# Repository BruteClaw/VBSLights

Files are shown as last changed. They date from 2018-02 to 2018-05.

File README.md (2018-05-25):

# VBSLights
Lighting modules for VBS

Designes are in KiCAD with corisponding Gerbers

Spec sheets on pertinant components

Code for the Raspberry Pi in Python

lightTest.py is a functional script to test the LEDs on device0

MQTT_Test.py is a functional script to test your MQTT Broker setup

MQTT_Lights.py is the full code that I have implemented on the Raspberry Pi that is in control of the lights

MQTT_Periodic_Test.py is a script that cycles through the commands of MQTT_Lights.py in order to stress test the configuration

MQTT_GUI.py is the code on the touch screen Pi in order to control the lights across the network

tkinter_test.py is some code that I was using to test the ability to make a GUI interface for the touchscreen

Videos of the design process:  https://www.youtube.com/playlist?list=PLKgBsJoH7_7Tdjw1KCGC1FjwnGFgput7B

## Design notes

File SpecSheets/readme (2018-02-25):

These are the spec sheets on components used in the circuit design

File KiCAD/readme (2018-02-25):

These are the project files for KiCAD on the circuit design and layout

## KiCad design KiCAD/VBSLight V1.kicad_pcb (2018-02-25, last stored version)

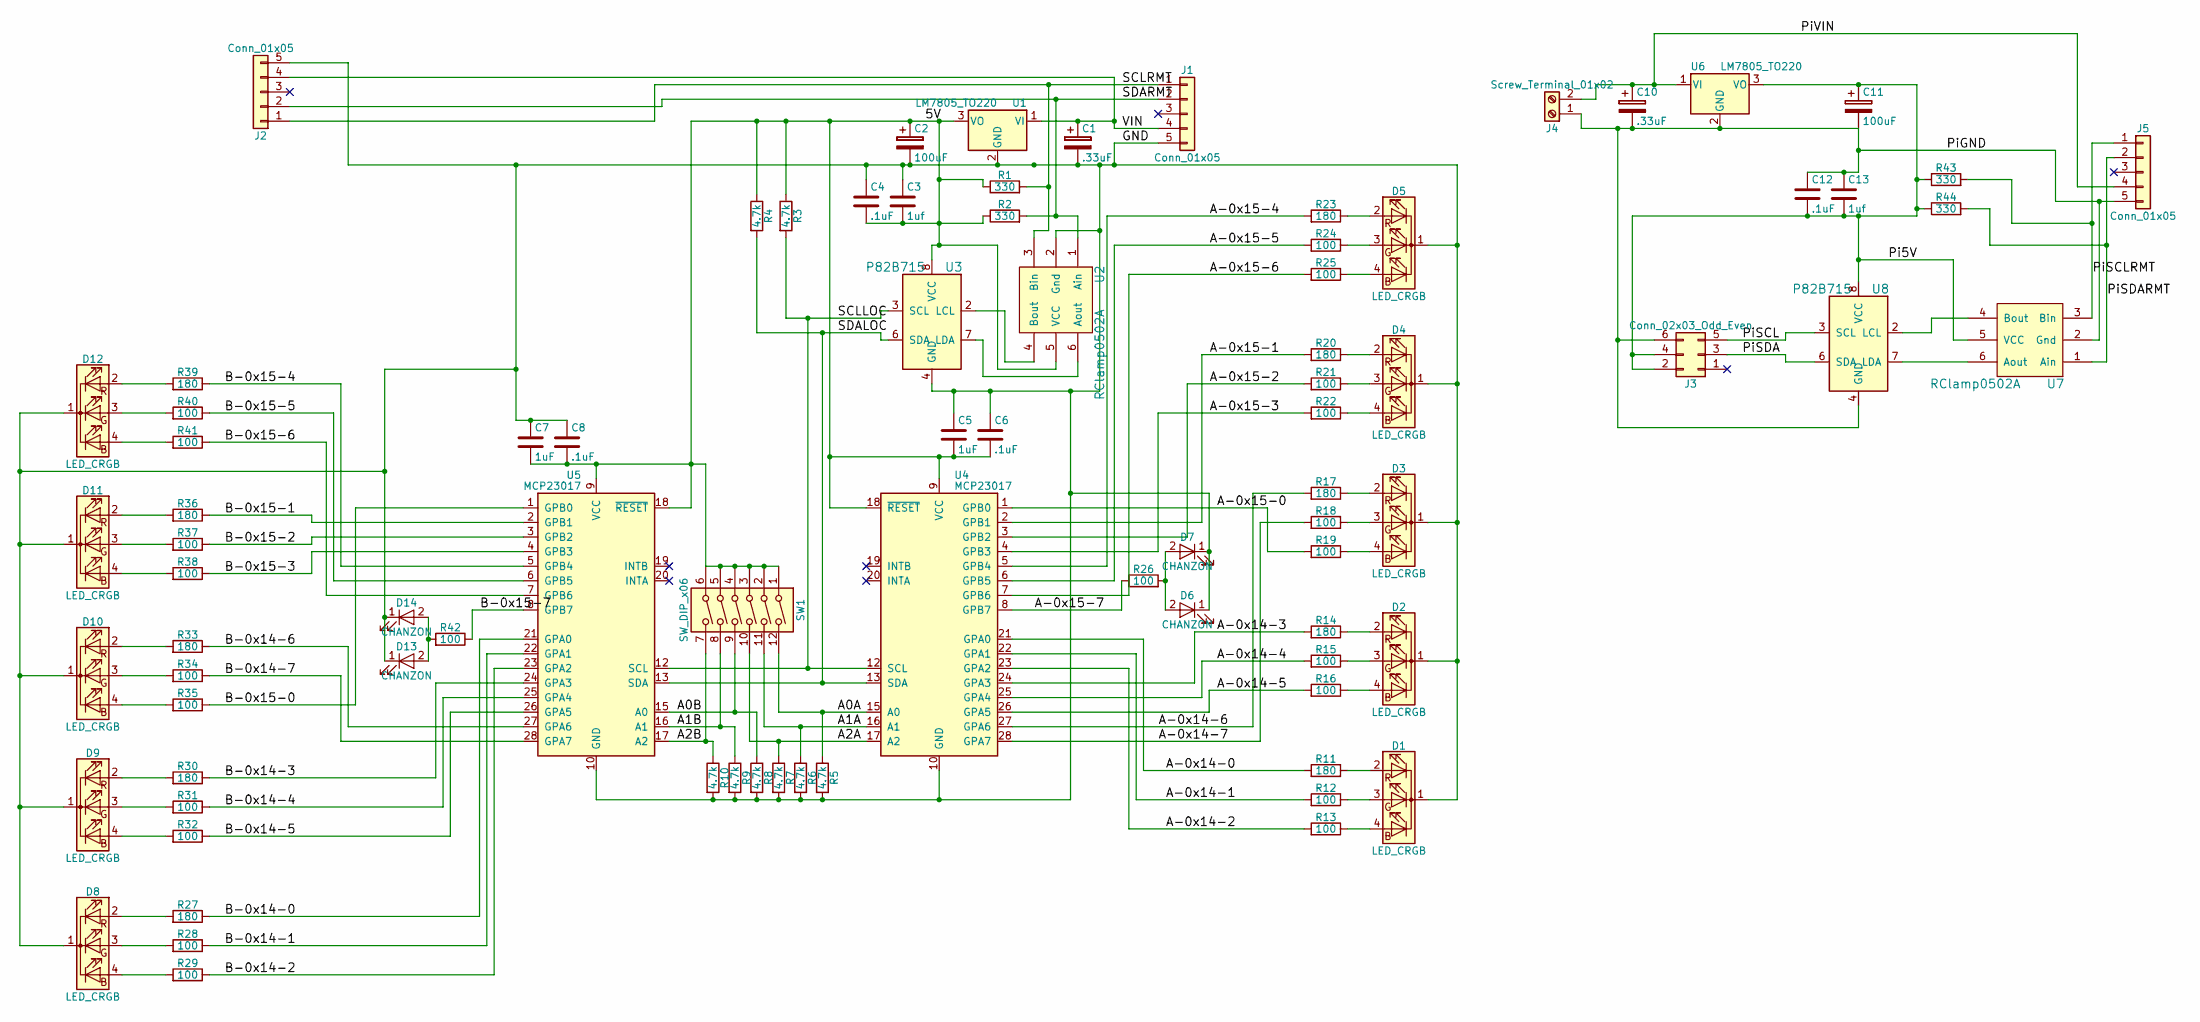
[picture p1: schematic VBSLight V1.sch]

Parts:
C1, C10: .33uF; CP_Radial_D4.0mm_P1.50mm
C2, C11: 100uF; CP_Radial_D4.0mm_P1.50mm
C3, C13: 1uf; C_1210_HandSoldering
C4, C6, C8, C12: .1uF; C_1210_HandSoldering
C5, C7: 1uF; C_1210_HandSoldering
D1, D2, D3, D4, D5, D8, D9, D10, D11, D12: LED_CRGB; LED_D5.0mm-4-Custom
D6, D7, D13, D14: CHANZON; LED_D5.0mm
J1, J2, J5: Conn_01x05; JST_XH_B05B-XH-A_05x2.50mm_Straight
J3: Conn_02x03_Odd_Even; Socket_Strip_Straight_2x03_Pitch2.54mm
J4: Screw_Terminal_01x02; TerminalBlock_Phoenix_MKDS1.5-2pol
R1, R2, R43, R44: 330; R_1210_HandSoldering
R3, R4, R5, R6, R7, R8, R9, R10: 4.7k; R_1210_HandSoldering
R11, R14, R17, R20, R23, R27, R30, R33, R36, R39: 180; R_1210_HandSoldering
R12, R13, R15, R16, R18, R19, R21, R22, R24, R25, R26, R28, R29, R31, R32, R34, R35, R37, R38, R40, R41, R42: 100; R_1210_HandSoldering
SW1: SW_DIP_x06; SW_DIP_x6_W7.62mm_Slide
U1, U6: LM7805_TO220; TO-220-3_Vertical
U2, U7: RClamp0502A; SOT-666_Handsolder
U3, U8: P82B715; SOIC-8-N
U4, U5: MCP23017; SOIC-28

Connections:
/5V: C2.1, C3.2, C4.2, C5.2, C6.2, C7.2, C8.2, R1.1, R2.1, R3.1, R4.1, SW1.1, SW1.2, SW1.3, SW1.4, SW1.5, SW1.6, U1.3 (VO), U2.5 (VCC), U3.8 (VCC), U4.9 (VCC), U4.18 (~RESET), U5.9 (VCC), U5.18 (~RESET)
/A0A: R5.1, SW1.12, U4.15 (A0)
/A0B: R8.1, SW1.9, U5.15 (A0)
/A1A: R6.1, SW1.11, U4.16 (A1)
/A1B: R9.1, SW1.8, U5.16 (A1)
/A2A: R7.1, SW1.10, U4.17 (A2)
/A2B: R10.1, SW1.7, U5.17 (A2)
/A-0x14-0: R11.2, U4.21 (GPA0)
/A-0x14-1: R12.2, U4.22 (GPA1)
/A-0x14-2: R13.2, U4.23 (GPA2)
/A-0x14-3: R14.2, U4.24 (GPA3)
/A-0x14-4: R15.2, U4.25 (GPA4)
/A-0x14-5: R16.2, U4.26 (GPA5)
/A-0x14-6: R17.2, U4.27 (GPA6)
/A-0x14-7: R18.2, U4.28 (GPA7)
/A-0x15-0: R19.2, U4.1 (GPB0)
/A-0x15-1: R20.2, U4.2 (GPB1)
/A-0x15-2: R21.2, U4.3 (GPB2)
/A-0x15-3: R22.2, U4.4 (GPB3)
/A-0x15-4: R23.2, U4.5 (GPB4)
/A-0x15-5: R24.2, U4.6 (GPB5)
/A-0x15-6: R25.2, U4.7 (GPB6)
/A-0x15-7: R26.1, U4.8 (GPB7)
/B-0x14-0: R27.1, U5.21 (GPA0)
/B-0x14-1: R28.1, U5.22 (GPA1)
/B-0x14-2: R29.1, U5.23 (GPA2)
/B-0x14-3: R30.1, U5.24 (GPA3)
/B-0x14-4: R31.1, U5.25 (GPA4)
/B-0x14-5: R32.1, U5.26 (GPA5)
/B-0x14-6: R33.1, U5.27 (GPA6)
/B-0x14-7: R34.1, U5.28 (GPA7)
/B-0x15-0: R35.1, U5.1 (GPB0)
/B-0x15-1: R36.1, U5.2 (GPB1)
/B-0x15-2: R37.1, U5.3 (GPB2)
/B-0x15-3: R38.1, U5.4 (GPB3)
/B-0x15-4: R39.1, U5.5 (GPB4)
/B-0x15-5: R40.1, U5.6 (GPB5)
/B-0x15-6: R41.1, U5.7 (GPB6)
/B-0x15-7: R42.1, U5.8 (GPB7)
/GND: C1.2, C2.2, C3.1, C4.1, C5.1, C6.1, C7.1, C8.1, D1.1 (K), D2.1 (K), D3.1 (K), D4.1 (K), D5.1 (K), D6.1 (K), D7.1 (K), D8.1 (K), D9.1 (K), D10.1 (K), D11.1 (K), D12.1 (K), D13.1 (K), D14.1 (K), J1.5, J2.5, R5.2, R6.2, R7.2, R8.2, R9.2, R10.2, U1.2 (GND), U2.2 (Gnd), U3.4 (GND), U4.10 (GND), U5.10 (GND)
/Pi5V: C11.1, C12.2, C13.2, J3.2, J3.4, R43.1, R44.1, U6.3 (VO), U7.5 (VCC), U8.8 (VCC); also elsewhere on the board
/PiGND: C10.2, C11.2, C12.1, C13.1, J3.6, J4.1, J5.5, U6.2 (GND), U7.2 (Gnd), U8.4 (GND)
/PiSCL: J3.5, U8.3 (SCL)
/PiSCLRMT: J5.1, R43.2, U7.3 (Bin)
/PiSDA: J3.3, U8.6 (SDA)
/PiSDARMT: J5.2, R44.2, U7.1 (Ain)
/PiVIN: C10.1, J4.2, J5.4, U6.1 (VI)
/SCLLOC: R3.2, U3.3 (SCL), U4.12 (SCL), U5.12 (SCL)
/SCLRMT: J1.1, J2.1, R1.2, U2.3 (Bin)
/SDALOC: R4.2, U3.6 (SDA), U4.13 (SDA), U5.13 (SDA)
/SDARMT: J1.2, J2.2, R2.2, U2.1 (Ain)
/VIN: C1.1, J1.4, J2.4, U1.1 (VI)
unnamed: D1.2 (RA), R11.1
unnamed: D1.3 (GA), R12.1
unnamed: D1.4 (BA), R13.1
unnamed: D2.2 (RA), R14.1
unnamed: D2.3 (GA), R15.1
unnamed: D2.4 (BA), R16.1
unnamed: D3.2 (RA), R17.1
unnamed: D3.3 (GA), R18.1
unnamed: D3.4 (BA), R19.1
unnamed: D4.2 (RA), R20.1
unnamed: D4.3 (GA), R21.1
unnamed: D4.4 (BA), R22.1
unnamed: D5.2 (RA), R23.1
unnamed: D5.3 (GA), R24.1
unnamed: D5.4 (BA), R25.1
unnamed: D6.2 (A), D7.2 (A), R26.2
unnamed: D8.2 (RA), R27.2
unnamed: D8.3 (GA), R28.2
unnamed: D8.4 (BA), R29.2
unnamed: D9.2 (RA), R30.2
unnamed: D9.3 (GA), R31.2
unnamed: D9.4 (BA), R32.2
unnamed: D10.2 (RA), R33.2
unnamed: D10.3 (GA), R34.2
unnamed: D10.4 (BA), R35.2
unnamed: D11.2 (RA), R36.2
unnamed: D11.3 (GA), R37.2
unnamed: D11.4 (BA), R38.2
unnamed: D12.2 (RA), R39.2
unnamed: D12.3 (GA), R40.2
unnamed: D12.4 (BA), R41.2
unnamed: D13.2 (A), D14.2 (A), R42.2
unnamed: U2.4 (Bout), U3.2 (LCL)
unnamed: U2.6 (Aout), U3.7 (LDA)
unnamed: U7.4 (Bout), U8.2 (LCL)
unnamed: U7.6 (Aout), U8.7 (LDA)

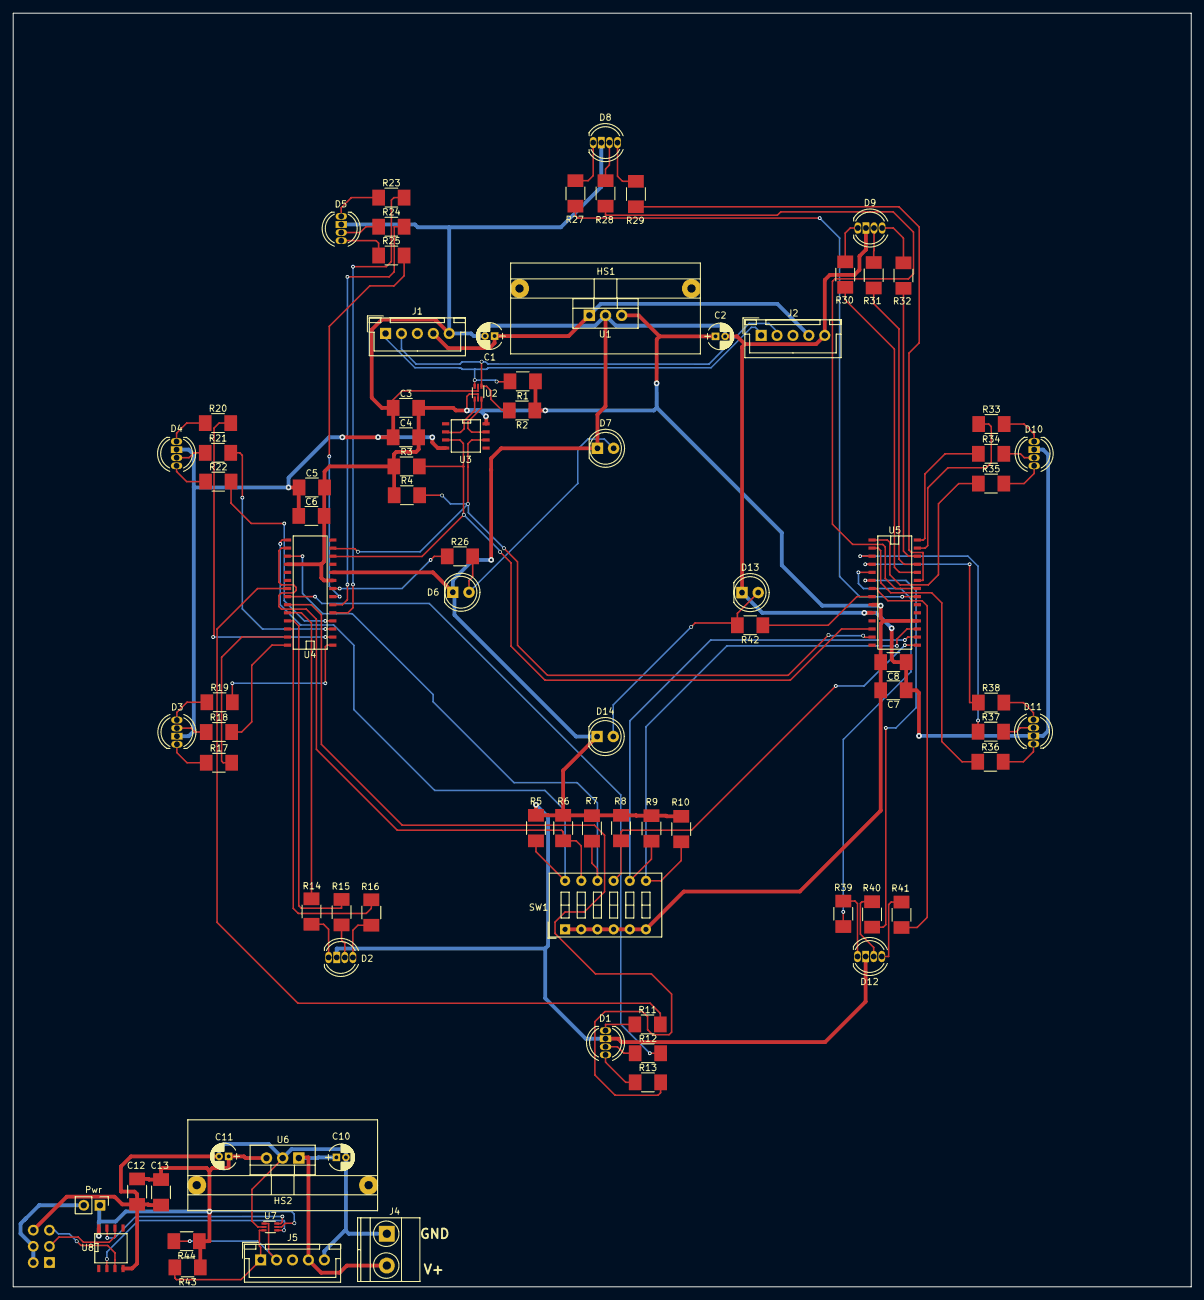
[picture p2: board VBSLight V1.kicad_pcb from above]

Board: 2 copper layers, 185.0 x 200.0 mm, 87 parts (1 on the bottom side), 88 nets.

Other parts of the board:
HS1, HS2: Heatsink_OHMITE_CSM222-30AE; Heatsink_Ohmite_CSM222-30AE
Pwr: Socket_Strip_Straight_1x02_Pitch2.54mm

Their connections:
/Pi5V: Pwr.1, Pwr.2; also elsewhere on the board

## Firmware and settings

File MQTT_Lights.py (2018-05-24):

#!/usr/bin/env python3

#imports
import smbus
import time
import socket
import random
import paho.mqtt.client as paho

#variables
bus       = smbus.SMBus(1) # use 1 for Rev 2 Pi, Use 0 for Rev 1 Pi
swirlTime = 0.1            # how quick the swirl patern runs
blinkTime = 0.2            # how fast the lights blink
broker    = "127.0.0.1"    # address of MQTT Broker
waitTime  = 10             # how long it waits before going Idle

# Device Addresses
devices = [ 0x20, 0x21, 0x22, 0x23, 0x24, 0x25, 0x26, 0x27, ]
# Use only one device for testing, comment out to use all
# devices = [ 0x20 ]

colors = [ "red", "yellow", "green", "blue", "purple", "white", "lightblue", ]

# Registers A are for GPA pins, Registers B are for GPB pins
IODIRA = 0x00 # Register A for pin direction
IODIRB = 0x01 # Register B for pin direction
OLATA  = 0x14 # Register A for outputs
OLATB  = 0x15 # Register B for outputs

banks = [ OLATA, OLATB, ]
random.seed()

#functions
def setup(device):
    # print(f"Setting up device #0x{device}")
    # Set GPA and GPB pins to outputs
    bus.write_byte_data(device,IODIRA,0x00)
    bus.write_byte_data(device,IODIRB,0x00)
    # Set all outputs to off
    bus.write_byte_data(device,OLATA,0x00)
    bus.write_byte_data(device,OLATB,0x00)
    #set lights to idle state
    idleState(device)

#light animations
def clear(addr):
    bus.write_byte_data(addr,OLATA,0x00)
    bus.write_byte_data(addr,OLATB,0x00)

def errorState():
    purpleBlink(devices[0])

def idleState(addr):
    bus.write_byte_data(addr,OLATB,0x80)

#Blinks
def redBlink(addr):
    bus.write_byte_data(addr,OLATA,0x49)
    bus.write_byte_data(addr,OLATB,0x12)
    time.sleep(blinkTime)
    bus.write_byte_data(addr,OLATA,0x00)
    bus.write_byte_data(addr,OLATB,0x00)
    time.sleep(blinkTime)

def blueBlink(addr):
    bus.write_byte_data(addr,OLATA,0x92)
    bus.write_byte_data(addr,OLATB,0x24)
    time.sleep(blinkTime)
    bus.write_byte_data(addr,OLATA,0x00)
    bus.write_byte_data(addr,OLATB,0x00)
    time.sleep(blinkTime)

def purpleBlink(addr):
    bus.write_byte_data(addr,OLATA,0xDB)
    bus.write_byte_data(addr,OLATB,0x36)
    time.sleep(blinkTime)
    bus.write_byte_data(addr,OLATA,0x00)
    bus.write_byte_data(addr,OLATB,0x00)
    time.sleep(blinkTime)

def greenBlink(addr):
    bus.write_byte_data(addr,OLATA,0x24)
    bus.write_byte_data(addr,OLATB,0x49)
    time.sleep(blinkTime)
    bus.write_byte_data(addr,OLATA,0x00)
    bus.write_byte_data(addr,OLATB,0x00)
    time.sleep(blinkTime)

def yellowBlink(addr):
    bus.write_byte_data(addr,OLATA,0x6D)
    bus.write_byte_data(addr,OLATB,0x5B)
    time.sleep(blinkTime)
    bus.write_byte_data(addr,OLATA,0x00)
    bus.write_byte_data(addr,OLATB,0x00)
    time.sleep(blinkTime)

def lightBlueBlink(addr):
    bus.write_byte_data(addr,OLATA,0xB6)
    bus.write_byte_data(addr,OLATB,0x6D)
    time.sleep(blinkTime)
    bus.write_byte_data(addr,OLATA,0x00)
    bus.write_byte_data(addr,OLATB,0x00)
    time.sleep(blinkTime)

def whiteBlink(addr):
    bus.write_byte_data(addr,OLATA,0xFF)
    bus.write_byte_data(addr,OLATB,0x7F)
    time.sleep(blinkTime)
    bus.write_byte_data(addr,OLATA,0x00)
    bus.write_byte_data(addr,OLATB,0x00)
    time.sleep(blinkTime)

#Swirls
def redSwirl(addr):
    bus.write_byte_data(addr,OLATA,0x01)
    time.sleep(swirlTime)
    bus.write_byte_data(addr,OLATA,0x08)
    time.sleep(swirlTime)
    bus.write_byte_data(addr,OLATA,0x40)
    time.sleep(swirlTime)
    bus.write_byte_data(addr,OLATA,0x00)
    bus.write_byte_data(addr,OLATB,0x02)
    time.sleep(swirlTime)
    bus.write_byte_data(addr,OLATB,0x10)
    time.sleep(swirlTime)
    bus.write_byte_data(addr,OLATB,0x00)
    time.sleep(swirlTime)

def blueSwirl(addr):
    bus.write_byte_data(addr,OLATA,0x02)
    time.sleep(swirlTime)
    bus.write_byte_data(addr,OLATA,0x10)
    time.sleep(swirlTime)
    bus.write_byte_data(addr,OLATA,0x80)
    time.sleep(swirlTime)
    bus.write_byte_data(addr,OLATA,0x00)
    bus.write_byte_data(addr,OLATB,0x04)
    time.sleep(swirlTime)
    bus.write_byte_data(addr,OLATB,0x20)
    time.sleep(swirlTime)
    bus.write_byte_data(addr,OLATB,0x00)
    time.sleep(swirlTime)

def greenSwirl(addr):
    bus.write_byte_data(addr,OLATA,0x04)
    time.sleep(swirlTime)
    bus.write_byte_data(addr,OLATA,0x20)
    time.sleep(swirlTime)
    bus.write_byte_data(addr,OLATA,0x00)
    bus.write_byte_data(addr,OLATB,0x01)
    time.sleep(swirlTime)
    bus.write_byte_data(addr,OLATB,0x08)
    time.sleep(swirlTime)
    bus.write_byte_data(addr,OLATB,0x40)
    time.sleep(swirlTime)
    bus.write_byte_data(addr,OLATB,0x00)
    time.sleep(swirlTime)

def purpleSwirl(addr):
    bus.write_byte_data(addr,OLATA,0x03)
    time.sleep(swirlTime)
    bus.write_byte_data(addr,OLATA,0x18)
    time.sleep(swirlTime)
    bus.write_byte_data(addr,OLATA,0xc0)
    time.sleep(swirlTime)
    bus.write_byte_data(addr,OLATA,0x00)
    bus.write_byte_data(addr,OLATB,0x06)
    time.sleep(swirlTime)
    bus.write_byte_data(addr,OLATB,0x30)
    time.sleep(swirlTime)
    bus.write_byte_data(addr,OLATB,0x00)
    time.sleep(swirlTime)

def yellowSwirl(addr):
    bus.write_byte_data(addr,OLATA,0x05)
    time.sleep(swirlTime)
    bus.write_byte_data(addr,OLATA,0x28)
    time.sleep(swirlTime)
    bus.write_byte_data(addr,OLATA,0x40)
    bus.write_byte_data(addr,OLATB,0x01)
    time.sleep(swirlTime)
    bus.write_byte_data(addr,OLATA,0x00)
    bus.write_byte_data(addr,OLATB,0x0A)
    time.sleep(swirlTime)
    bus.write_byte_data(addr,OLATB,0x50)
    time.sleep(swirlTime)
    bus.write_byte_data(addr,OLATB,0x00)
    time.sleep(swirlTime)

def lightBlueSwirl(addr):
    bus.write_byte_data(addr,OLATA,0x06)
    time.sleep(swirlTime)
    bus.write_byte_data(addr,OLATA,0x30)
    time.sleep(swirlTime)
    bus.write_byte_data(addr,OLATA,0x80)
    bus.write_byte_data(addr,OLATB,0x01)
    time.sleep(swirlTime)
    bus.write_byte_data(addr,OLATA,0x00)
    bus.write_byte_data(addr,OLATB,0x0C)
    time.sleep(swirlTime)
    bus.write_byte_data(addr,OLATB,0x60)
    time.sleep(swirlTime)
    bus.write_byte_data(addr,OLATB,0x00)
    time.sleep(swirlTime)

def whiteSwirl(addr):
    bus.write_byte_data(addr,OLATA,0x07)
    time.sleep(swirlTime)
    bus.write_byte_data(addr,OLATA,0x38)
    time.sleep(swirlTime)
    bus.write_byte_data(addr,OLATA,0xC0)
    bus.write_byte_data(addr,OLATB,0x01)
    time.sleep(swirlTime)
    bus.write_byte_data(addr,OLATA,0x00)
    bus.write_byte_data(addr,OLATB,0x0E)
    time.sleep(swirlTime)
    bus.write_byte_data(addr,OLATB,0x70)
    time.sleep(swirlTime)
    bus.write_byte_data(addr,OLATB,0x00)
    time.sleep(swirlTime)

#test sequince
def test():
    lightBlueBlink(devices[0])
    lightBlueSwirl(devices[0])
    idleState(devices[0])
    lightBlueBlink(devices[1])
    lightBlueSwirl(devices[1])
    idleState(devices[1])
    lightBlueBlink(devices[2])
    lightBlueSwirl(devices[2])
    idleState(devices[2])
    lightBlueBlink(devices[3])
    lightBlueSwirl(devices[3])
    idleState(devices[3])
    lightBlueBlink(devices[4])
    lightBlueSwirl(devices[4])
    idleState(devices[4])
    lightBlueBlink(devices[5])
    lightBlueSwirl(devices[5])
    idleState(devices[5])
    lightBlueBlink(devices[6])
    lightBlueSwirl(devices[6])
    idleState(devices[6])
    lightBlueBlink(devices[7])
    lightBlueSwirl(devices[7])
    idleState(devices[7])
    blueBlink(devices[0])
    blueSwirl(devices[0])
    idleState(devices[0])
    blueBlink(devices[1])
    blueSwirl(devices[1])
    idleState(devices[1])
    blueBlink(devices[2])
    blueSwirl(devices[2])
    idleState(devices[2])
    blueBlink(devices[3])
    blueSwirl(devices[3])
    idleState(devices[3])
    blueBlink(devices[4])
    blueSwirl(devices[4])
    idleState(devices[4])
    blueBlink(devices[5])
    blueSwirl(devices[5])
    idleState(devices[5])
    blueBlink(devices[6])
    blueSwirl(devices[6])
    idleState(devices[6])
    blueBlink(devices[7])
    blueSwirl(devices[7])
    idleState(devices[7])
    purpleBlink(devices[0])
    purpleSwirl(devices[0])
    idleState(devices[0])
    purpleBlink(devices[1])
    purpleSwirl(devices[1])
    idleState(devices[1])
    purpleBlink(devices[2])
    purpleSwirl(devices[2])
    idleState(devices[2])
    purpleBlink(devices[3])
    purpleSwirl(devices[3])
    idleState(devices[3])
    purpleBlink(devices[4])
    purpleSwirl(devices[4])
    idleState(devices[4])
    purpleBlink(devices[5])
    purpleSwirl(devices[5])
    idleState(devices[5])
    purpleBlink(devices[6])
    purpleSwirl(devices[6])
    idleState(devices[6])
    purpleBlink(devices[7])
    purpleSwirl(devices[7])
    idleState(devices[7])
    redBlink(devices[0])
    redSwirl(devices[0])
    idleState(devices[0])
    redBlink(devices[1])
    redSwirl(devices[1])
    idleState(devices[1])
    redBlink(devices[2])
    redSwirl(devices[2])
    idleState(devices[2])
    redBlink(devices[3])
    redSwirl(devices[3])
    idleState(devices[3])
    redBlink(devices[4])
    redSwirl(devices[4])
    idleState(devices[4])
    redBlink(devices[5])
    redSwirl(devices[5])
    idleState(devices[5])
    redBlink(devices[6])
    redSwirl(devices[6])
    idleState(devices[6])
    redBlink(devices[7])
    redSwirl(devices[7])
    idleState(devices[7])
    yellowBlink(devices[0])
    yellowSwirl(devices[0])
    idleState(devices[0])
    yellowBlink(devices[1])
    yellowSwirl(devices[1])
    idleState(devices[1])
    yellowBlink(devices[2])
    yellowSwirl(devices[2])
    idleState(devices[2])
    yellowBlink(devices[3])
    yellowSwirl(devices[3])
    idleState(devices[3])
    yellowBlink(devices[4])
    yellowSwirl(devices[4])
    idleState(devices[4])
    yellowBlink(devices[5])
    yellowSwirl(devices[5])
    idleState(devices[5])
    yellowBlink(devices[6])
    yellowSwirl(devices[6])
    idleState(devices[6])
    yellowBlink(devices[7])
    yellowSwirl(devices[7])
    idleState(devices[7])
    greenBlink(devices[0])
    greenSwirl(devices[0])
    idleState(devices[0])
    greenBlink(devices[1])
    greenSwirl(devices[1])
    idleState(devices[1])
    greenBlink(devices[2])
    greenSwirl(devices[2])
    idleState(devices[2])
    greenBlink(devices[3])
    greenSwirl(devices[3])
    idleState(devices[3])
    greenBlink(devices[4])
    greenSwirl(devices[4])
    idleState(devices[4])
    greenBlink(devices[5])
    greenSwirl(devices[5])
    idleState(devices[5])
    greenBlink(devices[6])
    greenSwirl(devices[6])
    idleState(devices[6])
    greenBlink(devices[7])
    greenSwirl(devices[7])
    idleState(devices[7])
    whiteBlink(devices[0])
    whiteSwirl(devices[0])
    idleState(devices[0])
    whiteBlink(devices[1])
    whiteSwirl(devices[1])
    idleState(devices[1])
    whiteBlink(devices[2])
    whiteSwirl(devices[2])
    idleState(devices[2])
    whiteBlink(devices[3])
    whiteSwirl(devices[3])
    idleState(devices[3])
    whiteBlink(devices[4])
    whiteSwirl(devices[4])
    idleState(devices[4])
    whiteBlink(devices[5])
    whiteSwirl(devices[5])
    idleState(devices[5])
    whiteBlink(devices[6])
    whiteSwirl(devices[6])
    idleState(devices[6])
    whiteBlink(devices[7])
    whiteSwirl(devices[7])
    idleState(devices[7])

#animations for years
def rampUp():
    allClear()
    bus.write_byte_data(devices[0],OLATA,0x05)
    bus.write_byte_data(devices[1],OLATA,0x05)
    time.sleep(swirlTime)
    bus.write_byte_data(devices[0],OLATA,0x28)
    bus.write_byte_data(devices[1],OLATA,0x28)
    bus.write_byte_data(devices[2],OLATA,0x05)
    time.sleep(swirlTime)
    bus.write_byte_data(devices[0],OLATA,0x40)
    bus.write_byte_data(devices[0],OLATB,0x01)
    bus.write_byte_data(devices[1],OLATA,0x40)
    bus.write_byte_data(devices[1],OLATB,0x01)
    bus.write_byte_data(devices[2],OLATA,0x28)
    bus.write_byte_data(devices[3],OLATA,0x05)
    time.sleep(swirlTime)
    bus.write_byte_data(devices[0],OLATA,0x00)
    bus.write_byte_data(devices[0],OLATB,0x0A)
    bus.write_byte_data(devices[1],OLATA,0x00)
    bus.write_byte_data(devices[1],OLATB,0x0A)
    bus.write_byte_data(devices[2],OLATA,0x40)
    bus.write_byte_data(devices[2],OLATB,0x01)
    bus.write_byte_data(devices[3],OLATA,0x28)
    bus.write_byte_data(devices[4],OLATA,0x05)
    time.sleep(swirlTime)
    bus.write_byte_data(devices[0],OLATB,0x50)
    bus.write_byte_data(devices[1],OLATB,0x50)
    bus.write_byte_data(devices[2],OLATA,0x00)
    bus.write_byte_data(devices[2],OLATB,0x0A)
    bus.write_byte_data(devices[3],OLATA,0x40)
    bus.write_byte_data(devices[3],OLATB,0x01)
    bus.write_byte_data(devices[4],OLATA,0x28)
    bus.write_byte_data(devices[5],OLATA,0x05)  
    time.sleep(swirlTime)
    bus.write_byte_data(devices[0],OLATB,0x00)
    bus.write_byte_data(devices[1],OLATB,0x00)
    bus.write_byte_data(devices[0],OLATA,0x05)
    bus.write_byte_data(devices[1],OLATA,0x05)
    bus.write_byte_data(devices[2],OLATB,0x50)
    bus.write_byte_data(devices[3],OLATA,0x00)
    bus.write_byte_data(devices[3],OLATB,0x0A)
    bus.write_byte_data(devices[4],OLATA,0x40)
    bus.write_byte_data(devices[4],OLATB,0x01)
    bus.write_byte_data(devices[5],OLATA,0x28)
    bus.write_byte_data(devices[6],OLATA,0x05) 
    time.sleep(swirlTime)
    bus.write_byte_data(devices[0],OLATA,0x28)
    bus.write_byte_data(devices[1],OLATA,0x28)
    bus.write_byte_data(devices[2],OLATB,0x00)
    bus.write_byte_data(devices[2],OLATA,0x05)
    bus.write_byte_data(devices[3],OLATB,0x50)
    bus.write_byte_data(devices[4],OLATA,0x00)
    bus.write_byte_data(devices[4],OLATB,0x0A)
    bus.write_byte_data(devices[5],OLATA,0x40)
    bus.write_byte_data(devices[5],OLATB,0x01)
    bus.write_byte_data(devices[6],OLATA,0x28)
    bus.write_byte_data(devices[7],OLATA,0x05)
    time.sleep(swirlTime)
    
def fullSwirl():
    bus.write_byte_data(devices[2],OLATA,0x28)
    bus.write_byte_data(devices[3],OLATB,0x00)
    bus.write_byte_data(devices[3],OLATA,0x05)
    bus.write_byte_data(devices[4],OLATB,0x50)
    bus.write_byte_data(devices[5],OLATA,0x00)
    bus.write_byte_data(devices[5],OLATB,0x0A)
    bus.write_byte_data(devices[6],OLATA,0x40)
    bus.write_byte_data(devices[6],OLATB,0x01)
    bus.write_byte_data(devices[7],OLATA,0x28)
    bus.write_byte_data(devices[1],OLATB,0x00)
    bus.write_byte_data(devices[1],OLATA,0x05)
    bus.write_byte_data(devices[0],OLATB,0x00)
    bus.write_byte_data(devices[0],OLATA,0x05)
    time.sleep(swirlTime)
    bus.write_byte_data(devices[3],OLATA,0x28)
    bus.write_byte_data(devices[4],OLATB,0x00)
    bus.write_byte_data(devices[4],OLATA,0x05)
    bus.write_byte_data(devices[5],OLATB,0x50)
    bus.write_byte_data(devices[6],OLATA,0x00)
    bus.write_byte_data(devices[6],OLATB,0x0A)
    bus.write_byte_data(devices[7],OLATA,0x40)
    bus.write_byte_data(devices[7],OLATB,0x01)
    bus.write_byte_data(devices[1],OLATA,0x28)
    bus.write_byte_data(devices[2],OLATB,0x00)
    bus.write_byte_data(devices[2],OLATA,0x05)
    bus.write_byte_data(devices[0],OLATA,0x28)
    time.sleep(swirlTime)
    bus.write_byte_data(devices[4],OLATA,0x28)
    bus.write_byte_data(devices[5],OLATB,0x00)
    bus.write_byte_data(devices[5],OLATA,0x05)
    bus.write_byte_data(devices[6],OLATB,0x50)
    bus.write_byte_data(devices[7],OLATA,0x00)
    bus.write_byte_data(devices[7],OLATB,0x0A)
    bus.write_byte_data(devices[1],OLATA,0x40)
    bus.write_byte_data(devices[1],OLATB,0x01)
    bus.write_byte_data(devices[2],OLATA,0x28)
    bus.write_byte_data(devices[3],OLATB,0x00)
    bus.write_byte_data(devices[3],OLATA,0x05)
    bus.write_byte_data(devices[0],OLATA,0x40)
    bus.write_byte_data(devices[0],OLATB,0x01)
    time.sleep(swirlTime)
    bus.write_byte_data(devices[5],OLATA,0x28)
    bus.write_byte_data(devices[6],OLATB,0x00)
    bus.write_byte_data(devices[6],OLATA,0x05)
    bus.write_byte_data(devices[7],OLATB,0x50)
    bus.write_byte_data(devices[1],OLATA,0x00)
    bus.write_byte_data(devices[1],OLATB,0x0A)
    bus.write_byte_data(devices[2],OLATA,0x40)
    bus.write_byte_data(devices[2],OLATB,0x01)
    bus.write_byte_data(devices[3],OLATA,0x28)
    bus.write_byte_data(devices[4],OLATB,0x00)
    bus.write_byte_data(devices[4],OLATA,0x05)
    bus.write_byte_data(devices[0],OLATA,0x00)
    bus.write_byte_data(devices[0],OLATB,0x0A)
    time.sleep(swirlTime)
    bus.write_byte_data(devices[6],OLATA,0x28)
    bus.write_byte_data(devices[7],OLATB,0x00)
    bus.write_byte_data(devices[7],OLATA,0x05)
    bus.write_byte_data(devices[1],OLATB,0x50)
    bus.write_byte_data(devices[2],OLATA,0x00)
    bus.write_byte_data(devices[2],OLATB,0x0A)
    bus.write_byte_data(devices[3],OLATA,0x40)
    bus.write_byte_data(devices[3],OLATB,0x01)
    bus.write_byte_data(devices[4],OLATA,0x28)
    bus.write_byte_data(devices[5],OLATB,0x00)
    bus.write_byte_data(devices[5],OLATA,0x05)
    bus.write_byte_data(devices[0],OLATB,0x50)
    time.sleep(swirlTime)
    bus.write_byte_data(devices[7],OLATA,0x28)
    bus.write_byte_data(devices[1],OLATB,0x00)
    bus.write_byte_data(devices[1],OLATA,0x05)
    bus.write_byte_data(devices[2],OLATB,0x50)
    bus.write_byte_data(devices[3],OLATA,0x00)
    bus.write_byte_data(devices[3],OLATB,0x0A)
    bus.write_byte_data(devices[4],OLATA,0x40)
    bus.write_byte_data(devices[4],OLATB,0x01)
    bus.write_byte_data(devices[5],OLATA,0x28)
    bus.write_byte_data(devices[6],OLATB,0x00)
    bus.write_byte_data(devices[6],OLATA,0x05)
    bus.write_byte_data(devices[0],OLATB,0x00)
    bus.write_byte_data(devices[0],OLATA,0x05)
    time.sleep(swirlTime)
    bus.write_byte_data(devices[1],OLATA,0x28)
    bus.write_byte_data(devices[2],OLATB,0x00)
    bus.write_byte_data(devices[2],OLATA,0x05)
    bus.write_byte_data(devices[3],OLATB,0x50)
    bus.write_byte_data(devices[4],OLATA,0x00)
    bus.write_byte_data(devices[4],OLATB,0x0A)
    bus.write_byte_data(devices[5],OLATA,0x40)
    bus.write_byte_data(devices[5],OLATB,0x01)
    bus.write_byte_data(devices[6],OLATA,0x28)
    bus.write_byte_data(devices[7],OLATB,0x00)
    bus.write_byte_data(devices[7],OLATA,0x05)
    bus.write_byte_data(devices[0],OLATA,0x28)
    time.sleep(swirlTime)

def blinks():
    allClear()
    randomBlink()
    randomBlink()
    randomBlink()
    randomBlink()
    randomBlink()
    randomBlink()
    randomBlink()
    randomBlink()
    randomBlink()
    randomBlink()
    randomBlink()
    randomBlink()
    randomBlink()
    randomBlink()
    randomBlink()
    randomBlink()
    randomBlink()
    randomBlink()
    
def randomBlink():
    c = colors[random.randint(0,6)]
    if c == "red":
        redBlink(devices[random.randint(0,7)])
    elif c == "green":
        greenBlink(devices[random.randint(0,7)])
    elif c == "blue":
        blueBlink(devices[random.randint(0,7)])
    elif c == "yellow":
        yellowBlink(devices[random.randint(0,7)])
    elif c == "purple":
        purpleBlink(devices[random.randint(0,7)])
    elif c == "lightblue":
        lightBlueBlink(devices[random.randint(0,7)])
    elif c == "white":
        whiteBlink(devices[random.randint(0,7)])
    else:
        allClear()
        errorState()
        allIdle()
    
def allIdle():
    allClear()
    idleState(devices[0])
    idleState(devices[1])
    idleState(devices[2])
    idleState(devices[3])
    idleState(devices[4])
    idleState(devices[5])
    idleState(devices[6])
    idleState(devices[7])
    
def allClear():
    clear(devices[7])
    clear(devices[6])
    clear(devices[5])
    clear(devices[4])
    clear(devices[3])
    clear(devices[2])
    clear(devices[1])
    clear(devices[0])

def fourKBC():
    allClear()
    bus.write_byte_data(devices[1],OLATA,0x24)
    bus.write_byte_data(devices[1],OLATB,0x49)

def threeKBC():
    allClear()
    bus.write_byte_data(devices[2],OLATA,0x24)
    bus.write_byte_data(devices[2],OLATB,0x49)
        
def twoKBC():
    allClear()
    bus.write_byte_data(devices[3],OLATA,0x24)
    bus.write_byte_data(devices[3],OLATB,0x49)    
    
def oneKBC():
    allClear()
    bus.write_byte_data(devices[4],OLATA,0x24)
    bus.write_byte_data(devices[4],OLATB,0x49)

def zero():
    allClear()
    bus.write_byte_data(devices[5],OLATA,0x24)
    bus.write_byte_data(devices[5],OLATB,0x49)

def oneKAD():
    allClear()
    bus.write_byte_data(devices[6],OLATA,0x24)
    bus.write_byte_data(devices[6],OLATB,0x49)

def twoKAD():
    allClear()
    bus.write_byte_data(devices[7],OLATA,0x24)
    bus.write_byte_data(devices[7],OLATB,0x49)

def fail():
    allClear()
    for x in range(14):
        redBlink(devices[random.randint(0,7)])
    bus.write_byte_data(devices[random.randint(0,7)],banks[random.randint(0,1)],random.randint(0,255))
    bus.write_byte_data(devices[random.randint(0,7)],banks[random.randint(0,1)],random.randint(0,255))
    bus.write_byte_data(devices[random.randint(0,7)],banks[random.randint(0,1)],random.randint(0,255))
    bus.write_byte_data(devices[random.randint(0,7)],banks[random.randint(0,1)],random.randint(0,255))
    bus.write_byte_data(devices[random.randint(0,7)],banks[random.randint(0,1)],random.randint(0,255))
    bus.write_byte_data(devices[random.randint(0,7)],banks[random.randint(0,1)],random.randint(0,255))

#MQTT On Connect
def on_connect(client, obj, flags, rc):
    print("Reconnecting: "+str(rc))
    print("Subscribing to 'lights'")
    client.subscribe("lights")
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

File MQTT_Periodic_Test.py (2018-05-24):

#!/usr/bin/env python

import time
import paho.mqtt.client as paho
broker="172.25.16.154"
port=1883

def on_publish(client,userdata,result):             #create function for callback
    print("data published")

def on_disconnect(client, userdata, rc):
    print("client disconnected ok")

    
pass

client1= paho.Client("control1")                    #create client object
client1.on_publish = on_publish                     #assign function to callback
client1.on_disconnect = on_disconnect
while True:
    client1.connect(broker,port)                        #establish connection
    ret= client1.publish("lights","fail")               #publish
    client1.disconnect()                                #disconnect until idle
    time.sleep(18)                                      #pause until Idle
    client1.connect(broker,port)                        #re-establish connection
    ret= client1.publish("lights","idle")               #publish Idle
    client1.disconnect()                                #disconnect until next cycle
    time.sleep(18)                                      #sleep until next command
    client1.connect(broker,port)                        #establish connection
    ret= client1.publish("lights","4000bc")             #publish
    client1.disconnect()                                #disconnect until idle
    time.sleep(18)                                      #pause until Idle
    client1.connect(broker,port)                        #re-establish connection
    ret= client1.publish("lights","idle")               #publish Idle
    client1.disconnect()                                #disconnect until next cycle
    time.sleep(18)                                      #sleep until next command
    client1.connect(broker,port)                        #establish connection
    ret= client1.publish("lights","3000bc")             #publish
    client1.disconnect()                                #disconnect until idle
    time.sleep(18)                                      #pause until Idle
    client1.connect(broker,port)                        #re-establish connection
    ret= client1.publish("lights","idle")               #publish Idle
    client1.disconnect()                                #disconnect until next cycle
    time.sleep(18)                                      #sleep until next command
    client1.connect(broker,port)                        #establish connection
    ret= client1.publish("lights","2000bc")             #publish
    client1.disconnect()                                #disconnect until idle
    time.sleep(18)                                      #pause until Idle
    client1.connect(broker,port)                        #re-establish connection
    ret= client1.publish("lights","idle")               #publish Idle
    client1.disconnect()                                #disconnect until next cycle
    time.sleep(18)                                      #sleep until next command
    client1.connect(broker,port)                        #establish connection
    ret= client1.publish("lights","1000bc")             #publish
    client1.disconnect()                                #disconnect until idle
    time.sleep(18)                                      #pause until Idle
    client1.connect(broker,port)                        #re-establish connection
    ret= client1.publish("lights","idle")               #publish Idle
    client1.disconnect()                                #disconnect until next cycle
    time.sleep(18)                                      #sleep until next command
    client1.connect(broker,port)                        #establish connection
    ret= client1.publish("lights","zero")               #publish
    client1.disconnect()                                #disconnect until idle
    time.sleep(18)                                      #pause until Idle
    client1.connect(broker,port)                        #re-establish connection
    ret= client1.publish("lights","idle")               #publish Idle
    client1.disconnect()                                #disconnect until next cycle
    time.sleep(18)                                      #sleep until next command
    client1.connect(broker,port)                        #establish connection
    ret= client1.publish("lights","1000ad")             #publish
    client1.disconnect()                                #disconnect until idle
    time.sleep(18)                                      #pause until Idle
    client1.connect(broker,port)                        #re-establish connection
    ret= client1.publish("lights","idle")               #publish Idle
    client1.disconnect()                                #disconnect until next cycle
    time.sleep(18)                                      #sleep until next command
    client1.connect(broker,port)                        #establish connection
    ret= client1.publish("lights","2000ad")             #publish
    client1.disconnect()                                #disconnect until idle
    time.sleep(18)                                      #pause until Idle
    client1.connect(broker,port)                        #re-establish connection
    ret= client1.publish("lights","idle")               #publish Idle
    client1.disconnect()                                #disconnect until next cycle
    time.sleep(18)                                      #sleep until next command

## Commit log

2018-02-25 Initial commit of files
    [VBSLight V1-B.Cu.gbl, VBSLight V1-B.Mask.gbs, VBSLight V1-Edge.Cuts.gm1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]
2018-03-11 Add files via upload
    Updated version to correct for errors in prior versions including size of the circuit board
2018-06-03 Updated GUI Files
    Changed the GUI to have bigger buttons and separated the sound effects out by day they are going to be used
